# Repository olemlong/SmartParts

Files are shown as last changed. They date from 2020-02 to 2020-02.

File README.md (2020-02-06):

# SmartParts
A smart and glowing storage system for electronic components.  

https://www.youtube.com/watch?v=v1Y57d32keY

Ever since I started working with electronics, the pile of parts has been growing to the point where it took forever to find the correct part. The first step in solving this madnes was to get a cabinet and labelmaker. 
With the cabinet stacked with components, and each drawer labeled, I saw the problem as history.

As a few months passed by, the cabinet was full and i needed another cabinet to store more parts. Bought another cabinet, labeled each drawer with the components that was inside. This repeated itself until i had six cabinets all labeled. 

Now instead of searching in a desk drawer filled with all kinds of parst, i searched 6 cabinets for the correct labeled drawer. This became a pain. So i started thinking of a system that could indicate the correct drawer based on a search. This is when the SmartParts system was born.



The hardware requirements:  
-Raspberry Pi (for running the MySql and MQTT server)  
-Esp8266 controller (one controller for each cabinet)  
-WS2812b LED (one for each drawer)  
-LED PCB (one for each row in the cabinet)  
-WiFi

PCB

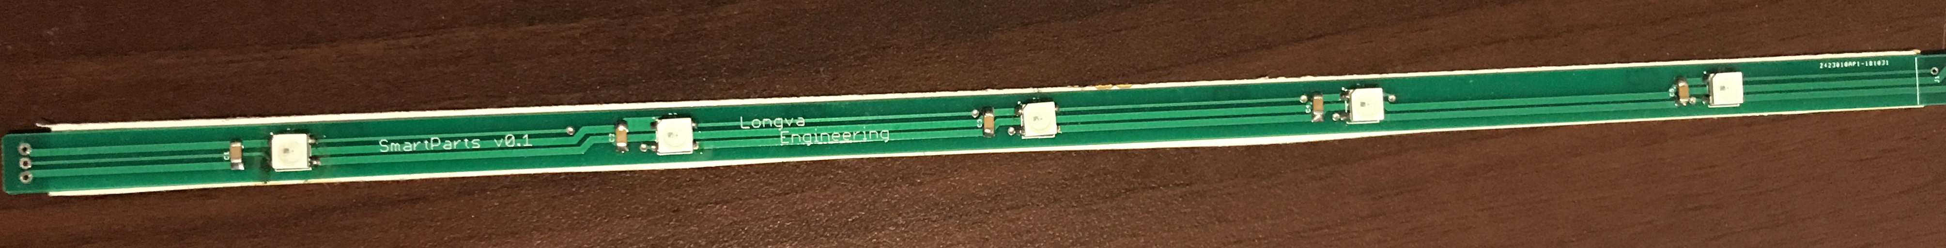
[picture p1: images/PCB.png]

  
The LED PCB is optional. You could always buy a roll of the WS2812b leds on ebay and cut it to length. Just a warning, this is what i did in the first cabinet and why i designed the PCB, it is alot of work, the double sided tape falls off and it is a bitch to cut and solder each led.

Cabinet controller (ESP8266)  



This controls the cabinet. When the controller connects to the wifi network, the controller is ready for data input.  
It subscribes to a topic that coresponds to the cabinet number. When the client software publishes data on this topic, the controller will light up leds according to this data. I use one 230v -> 5v 1A power supply for each cabinet (2 pin plug). The 3 pin plug is 5v, GND and data for the leds.  

Server 

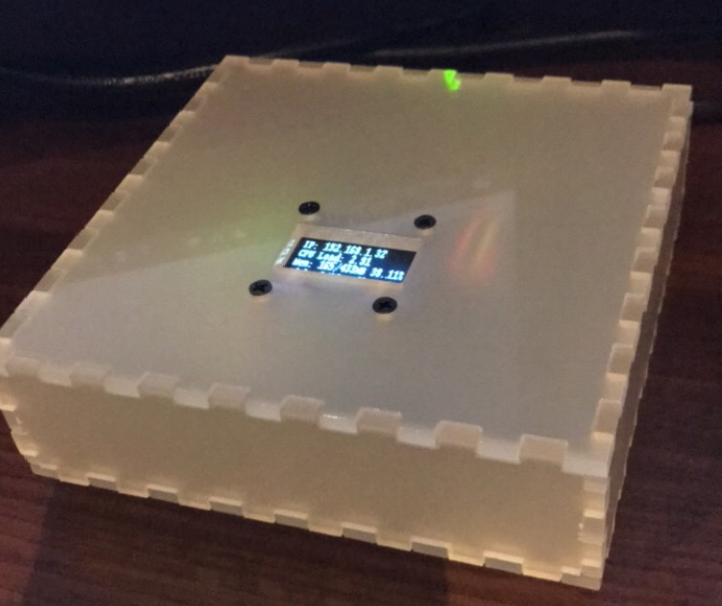
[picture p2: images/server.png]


I built a little casing for my Raspberry with a screen showing load and IP address.  
You can use whatever casing you want.  You can run what image you want, as long as it runs an MySql server and an MQTT server.

Cabinet layout
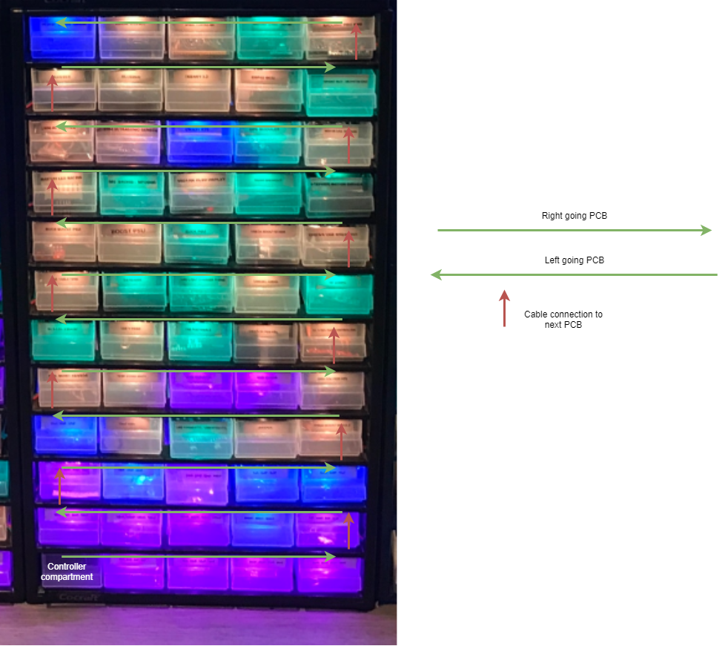
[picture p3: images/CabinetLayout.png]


PCB mounting in cabinet
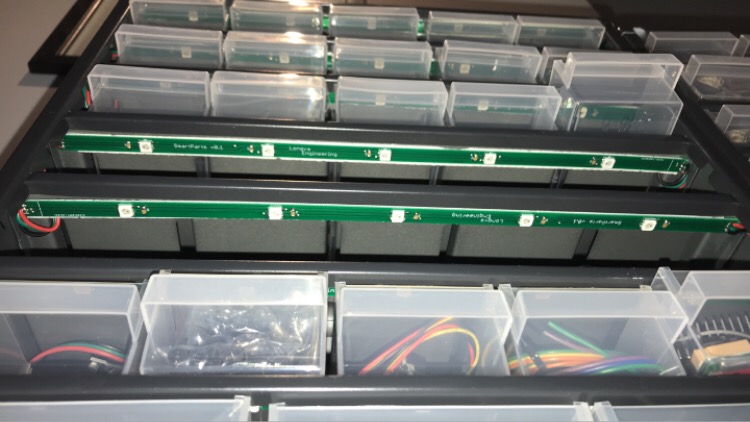
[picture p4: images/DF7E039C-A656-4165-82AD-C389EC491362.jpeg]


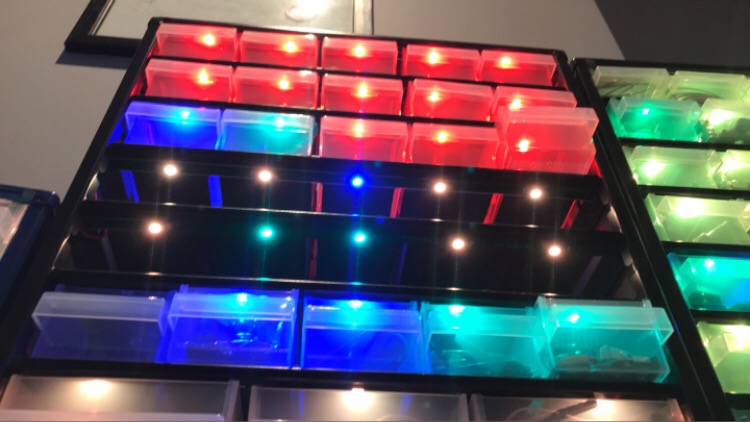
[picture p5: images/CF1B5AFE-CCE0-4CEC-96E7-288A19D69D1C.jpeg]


Software requirements:
Arduino IDE with support for ESP8266 + some libs (se source)
Python 3 with paho mqtt, mysql connector and PyQy5.  
   
How it all works  
  
  All the parts are stored in a MySql database. Each part has coordinates coresponding to the placement in the cabinets, like an address. This address is composed of four values (W,X,Y,Z).  
W -The cabinet coordinate. 1 = cabinet 1, 2 = cabinet 2, and so on.  
X -The column coordinate. 1 = column 1, 2 = column 2, and so on. I only have 5 columns in my cabinets.  
Y -The row coordinate. 1 = row 1, 2 = row 2, and so on.   
Z -The compartment coordinate. Each drawer can be devided into 4 compartments.   

The Flow of data.  

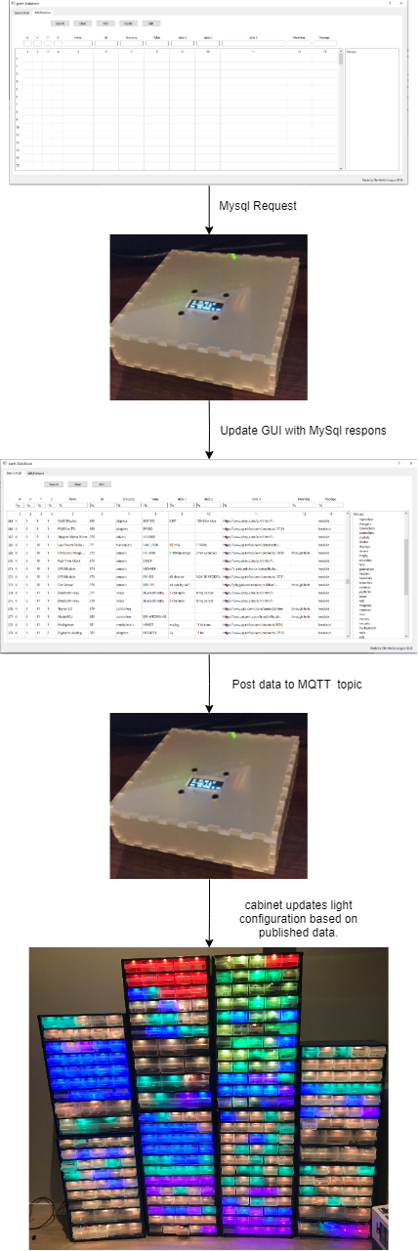
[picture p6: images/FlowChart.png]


Whats with the colors?  
When a search is done, the drawers light up with a color. The color indicates the compartment in the drawer the component is in.  
Red empty drawer.  
Yellow first compartment.  
Green second compartment.  
Blue third compartment.  
Purple forth compartment.

https://www.youtube.com/watch?v=v1Y57d32keY

https://www.youtube.com/watch?v=QyOVx2Oqz8I

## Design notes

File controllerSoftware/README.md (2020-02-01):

controller software.

you will need to setup the source with wifi SSID, password.   
It also needs data on how many leds it is controlling, cabinet number and so on.

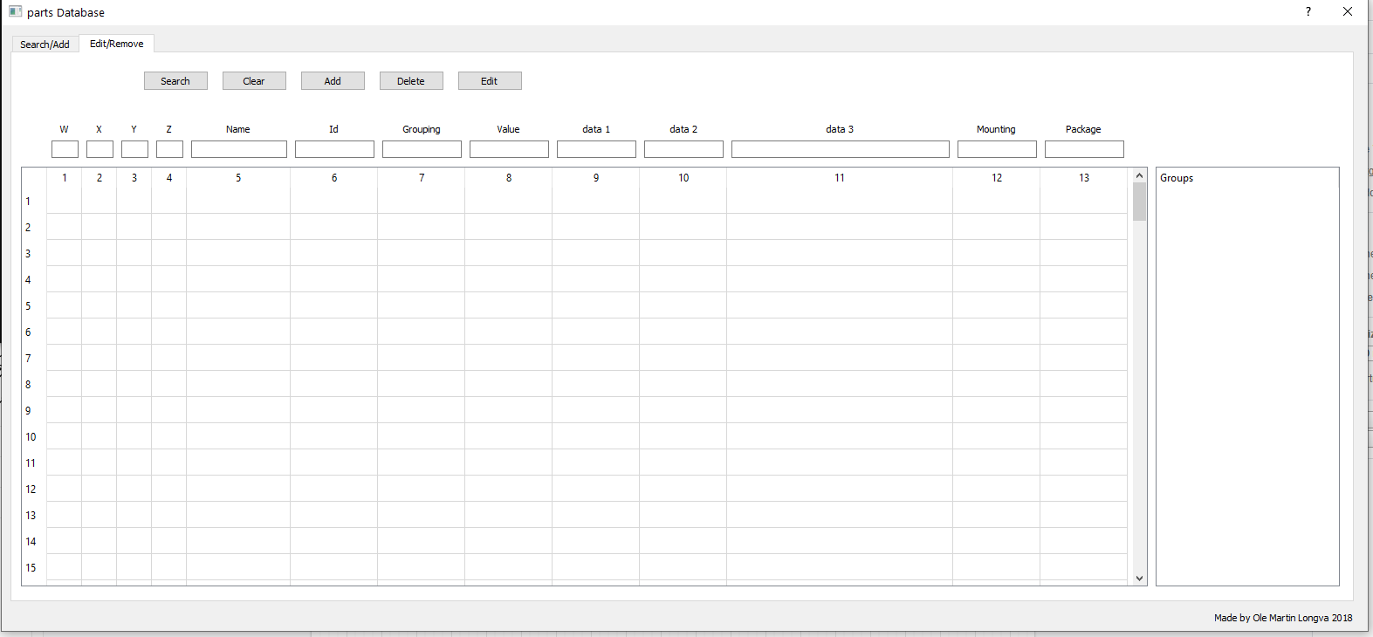
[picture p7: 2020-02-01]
images/emptyGui.png

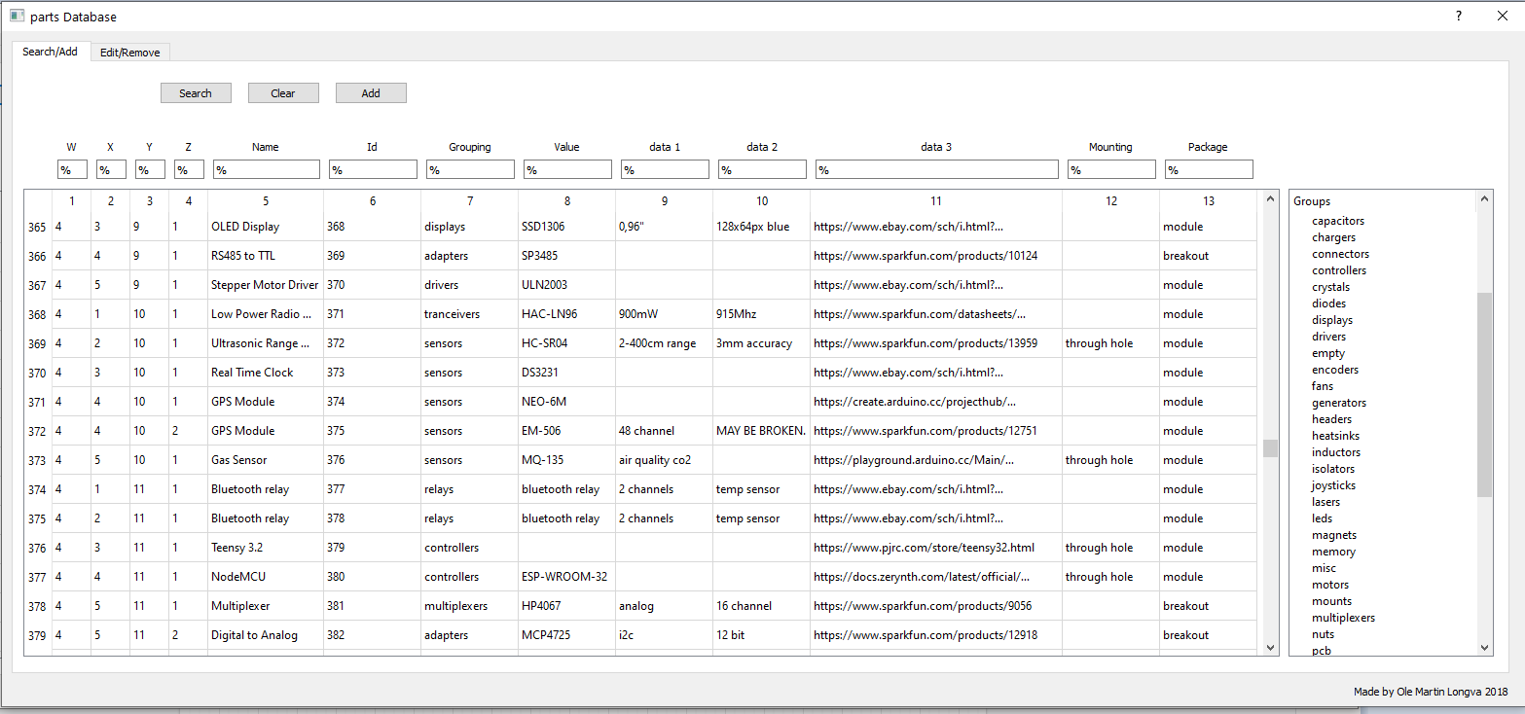
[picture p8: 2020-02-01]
images/gui.png

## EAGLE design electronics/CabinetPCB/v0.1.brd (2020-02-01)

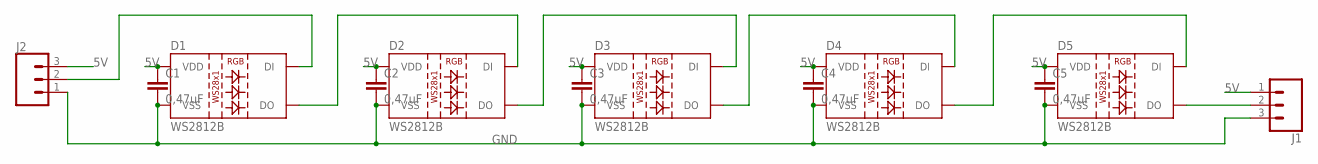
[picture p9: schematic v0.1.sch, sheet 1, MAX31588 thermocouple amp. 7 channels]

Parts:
C1, C2, C3, C4, C5: 0,47uF; 1206
D1, D2, D3, D4, D5: WS2812B
J1, J2: CONN_03JST-PTH; JST-3-PTH

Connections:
5V: C1.1, C2.1, C3.1, C4.1, C5.1, D1.1 (VDD), D2.1 (VDD), D3.1 (VDD), D4.1 (VDD), D5.1 (VDD), J1.1, J2.3
GND: C1.2, C2.2, C3.2, C4.2, C5.2, D1.3 (VSS), D2.3 (VSS), D3.3 (VSS), D4.3 (VSS), D5.3 (VSS), J1.3, J2.1
unnamed: D1.2 (DO), D2.4 (DI)
unnamed: D2.2 (DO), D3.4 (DI)
unnamed: D3.2 (DO), D4.4 (DI)
unnamed: D4.2 (DO), D5.4 (DI)
unnamed: D5.2 (DO), J1.2
unnamed: D1.4 (DI), J2.2

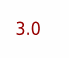
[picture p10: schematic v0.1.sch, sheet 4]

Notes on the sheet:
3.0

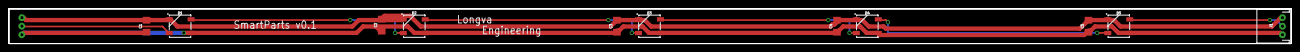
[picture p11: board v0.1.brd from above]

Board: 2 copper layers, 300.5 x 8.1 mm, 12 parts (1 on the bottom side), 8 nets.

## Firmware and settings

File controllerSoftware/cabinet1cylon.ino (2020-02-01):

#include <FastLED.h>
#include <ESP8266WiFi.h>
#include <PubSubClient.h>
#include <ESP8266mDNS.h>
#include <WiFiUdp.h>
#include <ArduinoOTA.h>

//if your cabinet has less or more, this must be changed.
#define NUM_LEDS 60

// Data pin that led data will be written out over
#define LED_PIN 14

// Clock pin only needed for SPI based chipsets when not using hardware SPI
#define COLOR_ORDER GRB

#define CHIPSET     WS2812

#define COOLING  55
#define FRAMES_PER_SECOND 60
#define SPARKING 120
#define BRIGHTNESS 200

//this needs to be unique for each cabinet. use these setting only for your first cabinet.
#define CONTROLLERNAME "smartPartsCabinet1"
#define SUBTOPIC "parts/cabinet1"
#define WATCHDOGTOPIC "parts/watchdog1"

// Params for rows and columns.
const uint8_t kMatrixWidth = 5;
const uint8_t kMatrixHeight = 9;

WiFiClient espClient;
PubSubClient client(espClient);


// Change the credentials below, so your ESP8266 connects to your router
const char* ssid = "";
const char* password = "";
const char* mqtt_server = "";

// Param for different pixel layouts
const bool    kMatrixSerpentineLayout = true;
// Set 'kMatrixSerpentineLayout' to false if your pixels are
// laid out all running the same way, like this:
//
//     0 >  1 >  2 >  3 >  4
//                         |
//     .----<----<----<----'
//     |
//     5 >  6 >  7 >  8 >  9
//                         |
//     .----<----<----<----'
//     |
//    10 > 11 > 12 > 13 > 14
//                         |
//     .----<----<----<----'
//     |
//    15 > 16 > 17 > 18 > 19
//
// Set 'kMatrixSerpentineLayout' to true if your pixels are
// laid out back-and-forth, like this:
//
//     0 >  1 >  2 >  3 >  4
//                         |
//                         |
//     9 <  8 <  7 <  6 <  5
//     |
//     |
//    10 > 11 > 12 > 13 > 14
//                        |
//                        |
//    19 < 18 < 17 < 16 < 15
//

#define NUM_LEDS (kMatrixWidth * kMatrixHeight)
CRGB leds_plus_safety_pixel[ NUM_LEDS + 1];
CRGB* const leds( leds_plus_safety_pixel + 1);

int fire = 0;
bool gReverseDirection = false;

void setup() {
  FastLED.addLeds<CHIPSET, LED_PIN, COLOR_ORDER>(leds, NUM_LEDS).setCorrection( TypicalLEDStrip );


  FastLED.setBrightness( BRIGHTNESS );

  Serial.begin(115200);
  setup_wifi();
  ArduinoOTA.setHostname(CONTROLLERNAME);
  ArduinoOTA.onStart([]() {
    String type;
    if (ArduinoOTA.getCommand() == U_FLASH) {
      type = "sketch";
    } else { // U_SPIFFS
      type = "filesystem";
    }

    // NOTE: if updating SPIFFS this would be the place to unmount SPIFFS using SPIFFS.end()
    Serial.println("Start updating " + type);
  });
  ArduinoOTA.onEnd([]() {
    Serial.println("\nEnd");
  });
  ArduinoOTA.onProgress([](unsigned int progress, unsigned int total) {
    Serial.printf("Progress: %u%%\r", (progress / (total / 100)));
  });
  ArduinoOTA.onError([](ota_error_t error) {
    Serial.printf("Error[%u]: ", error);
    if (error == OTA_AUTH_ERROR) {
      Serial.println("Auth Failed");
    } else if (error == OTA_BEGIN_ERROR) {
      Serial.println("Begin Failed");
    } else if (error == OTA_CONNECT_ERROR) {
      Serial.println("Connect Failed");
    } else if (error == OTA_RECEIVE_ERROR) {
      Serial.println("Receive Failed");
    } else if (error == OTA_END_ERROR) {
      Serial.println("End Failed");
    }
  });
  ArduinoOTA.begin();
  Serial.println("Ready");
  Serial.print("IP address: ");
  Serial.println(WiFi.localIP());

  client.setServer(mqtt_server, 1883);
  client.setCallback(callback);

  moveSingleLED();
}

int i = 0;
void loop()
{
  ArduinoOTA.handle();
  if (!client.connected()) {
    reconnect();
  }
  if (!client.loop())
    client.connect(CONTROLLERNAME);


  if (fire == 1) {
    Fire2012(); // run simulation frame
    FastLED.show(); // display this frame
    FastLED.delay(1000 / FRAMES_PER_SECOND);

  }
  if (fire == 2) {
    cylon();
  }
  
  if (i > 253) {
    i = 0;
  }
  i++;
  delay(10);
}

uint16_t XY( uint8_t x, uint8_t y)
{
  uint16_t i;

  if ( kMatrixSerpentineLayout == false) {
    i = (y * kMatrixWidth) + x;
  }

  if ( kMatrixSerpentineLayout == true) {
    if ( y & 0x01) {
      // Odd rows run backwards
      uint8_t reverseX = (kMatrixWidth - 1) - x;
      i = (y * kMatrixWidth) + reverseX;
    } else {
      // Even rows run forwards
      i = (y * kMatrixWidth) + x;
    }
  }

  return i;
}

uint16_t XYsafe( uint8_t x, uint8_t y)
{
  if ( x >= kMatrixWidth) return -1;
  if ( y >= kMatrixHeight) return -1;
  return XY(x, y);
}

// This functions is executed when some device publishes a message to a topic that your ESP8266 is subscribed to
// Change the function below to add logic to your program, so when a device publishes a message to a topic that
// your ESP8266 is subscribed you can actually do something
void callback(String topic, byte* message, unsigned int length) {
  Serial.print("Message arrived on topic: ");
  Serial.print(topic);
  Serial.print(". Message: ");
  String messageTemp;

  for (int i = 0; i < length; i++) {
    Serial.print((char)message[i]);
    messageTemp += (char)message[i];
  }
  Serial.println();

  // Feel free to add more if statements to control more GPIOs with MQTT

  // If a message is received on the topic kjellerstue/lamp, you check if the message is either on or off. Turns the lamp GPIO according to the message
  if (topic == SUBTOPIC) {
    if (messageTemp == "E") {
      FastLED.show();
      Serial.println("updating led with new frame");
      FastLED.clear();
    }
    if (messageTemp == "fire") {
      fire = 1;
    }
    if (messageTemp == "water") {
      fire = 0;
      FastLED.clear();
      FastLED.show();
    }
    if (messageTemp == "cylon") {
      fire = 2;
      FastLED.clear();
      FastLED.show();
    }
    else {
      Serial.print("X: ");
      Serial.print(getValue(messageTemp, ' ', 0));
      Serial.print(" Y: ");
      Serial.print(getValue(messageTemp, ' ', 1));
      Serial.print(" Z: ");
      Serial.print(getValue(messageTemp, ' ', 2));


      // Here's the x, y to 'led index' in action:
      leds[ XY( getValue(messageTemp, ' ', 0).toInt() - 1, getValue(messageTemp, ' ', 1).toInt() - 1) ] = CHSV( getValue(messageTemp, ' ', 2).toInt() * 50, 255, 255);
    }


  }
  if (topic == WATCHDOGTOPIC) {
    if (messageTemp == "woff, woff...") {
      Serial.println(messageTemp);
      client.publish(WATCHDOGTOPIC, "mjau!");
    }
    if (messageTemp == "test") {
      Serial.println(messageTemp);
      client.publish(WATCHDOGTOPIC, "blink!");
      moveSingleLED();
    }
  }
  Serial.println();
}

// This functions reconnects your ESP8266 to your MQTT broker
// Change the function below if you want to subscribe to more topics with your ESP8266
void reconnect() {
  // Loop until we're reconnected
  while (!client.connected()) {
    Serial.print("Attempting MQTT connection...");
    // Attempt to connect
    /*
      YOU MIGHT NEED TO CHANGE THIS LINE, IF YOU'RE HAVING PROBLEMS WITH MQTT MULTIPLE CONNECTIONS
      To change the ESP device ID, you will have to give a new name to the ESP8266.
      Here's how it looks:
       if (client.connect("ESP8266Client")) {
      You can do it like this:
       if (client.connect("ESP1_Office")) {
      Then, for the other ESP:
       if (client.connect("ESP2_Garage")) {
      That should solve your MQTT multiple connections problem
    */
    if (client.connect(CONTROLLERNAME)) {
      Serial.println("connected");
      // Subscribe or resubscribe to a topic
      // You can subscribe to more topics (to control more LEDs in this example)
      client.subscribe(SUBTOPIC);
      client.subscribe(WATCHDOGTOPIC);
    } else {
      Serial.print("failed, rc=");
      Serial.print(client.state());
      Serial.println(" try again in 5 seconds");
      // Wait 5 seconds before retrying
      delay(5000);
    }
  }
}
void setup_wifi() {
  delay(10);
  // We start by connecting to a WiFi network
  Serial.println();
  Serial.print("Connecting to ");
  Serial.println(ssid);
  WiFi.begin(ssid, password);
  while (WiFi.status() != WL_CONNECTED) {
    delay(500);
    Serial.print(".");
  }
  Serial.println("");
  Serial.print("WiFi connected - ESP IP address: ");
  Serial.println(WiFi.localIP());
}

String getValue(String data, char separator, int index)
{
  int found = 0;
  int strIndex[] = {0, -1};
  int maxIndex = data.length() - 1;

  for (int i = 0; i <= maxIndex && found <= index; i++) {
    if (data.charAt(i) == separator || i == maxIndex) {
      found++;
      strIndex[0] = strIndex[1] + 1;
      strIndex[1] = (i == maxIndex) ? i + 1 : i;
    }
  }

  return found > index ? data.substring(strIndex[0], strIndex[1]) : "";
}

void moveSingleLED() {
  // Move a single white led
  for (int whiteLed = 0; whiteLed < NUM_LEDS; whiteLed = whiteLed + 1) {
    // Turn our current led on to white, then show the leds
    leds[whiteLed] = CRGB::White;

    // Show the leds (only one of which is set to white, from above)
    FastLED.show();

    // Wait a little bit
    delay(100);

    // Turn our current led back to black for the next loop around
    leds[whiteLed] = CRGB::Black;
  }
}
void Fire2012()
{
  // Array of temperature readings at each simulation cell
  static byte heat[NUM_LEDS];

  // Step 1.  Cool down every cell a little
  for ( int i = 0; i < NUM_LEDS; i++) {
    heat[i] = qsub8( heat[i],  random8(0, ((COOLING * 10) / NUM_LEDS) + 2));
  }

  // Step 2.  Heat from each cell drifts 'up' and diffuses a little
  for ( int k = NUM_LEDS - 1; k >= 2; k--) {
    heat[k] = (heat[k - 1] + heat[k - 2] + heat[k - 2] ) / 3;
  }

  // Step 3.  Randomly ignite new 'sparks' of heat near the bottom
  if ( random8() < SPARKING ) {
    int y = random8(7);
    heat[y] = qadd8( heat[y], random8(160, 255) );
  }

  // Step 4.  Map from heat cells to LED colors
  for ( int j = 0; j < NUM_LEDS; j++) {
    CRGB color = HeatColor( heat[j]);
    int pixelnumber;
    if ( gReverseDirection ) {
      pixelnumber = (NUM_LEDS - 1) - j;
    } else {
      pixelnumber = j;
    }
    leds[pixelnumber] = color;
  }
}
void fadeall() { for(int i = 0; i < NUM_LEDS; i++) { leds[i].nscale8(250); } }
void cylon() {
  static uint8_t hue = 0;
  Serial.print("x");
  // First slide the led in one direction
  for(int i = 0; i < NUM_LEDS; i++) {
    // Set the i'th led to red 
    leds[i] = CHSV(hue++, 255, 255);
    // Show the leds
    FastLED.show(); 
    // now that we've shown the leds, reset the i'th led to black
    // leds[i] = CRGB::Black;
    fadeall();
    // Wait a little bit before we loop around and do it again
    delay(10);
  }
  Serial.print("x");

  // Now go in the other direction.  
  for(int i = (NUM_LEDS)-1; i >= 0; i--) {
    // Set the i'th led to red 
    leds[i] = CHSV(hue++, 255, 255);
    // Show the leds
    FastLED.show();
    // now that we've shown the leds, reset the i'th led to black
    // leds[i] = CRGB::Black;
    fadeall();
    // Wait a little bit before we loop around and do it again
    delay(10);
  }
}

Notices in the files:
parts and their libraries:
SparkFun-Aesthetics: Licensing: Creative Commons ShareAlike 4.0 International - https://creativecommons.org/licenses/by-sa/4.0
